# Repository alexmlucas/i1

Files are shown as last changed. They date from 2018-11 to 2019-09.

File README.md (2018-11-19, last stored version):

# i1
An accessible motion based guitar instrument

This project is part of PhD Research being undertaken by Queens University Belfast. 

i1 is a bespoke instrument designed for and with a musician with a physical disability. The intial concept is for the musician to use head and arm movement to trigger playback of chords on a virtual guitar.

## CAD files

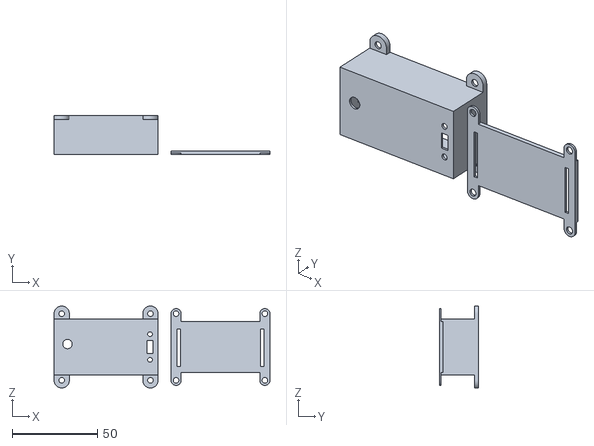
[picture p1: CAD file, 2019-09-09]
mechanical_design/wristband_enclosure.stl
126.5 x 23.0 x 48.0

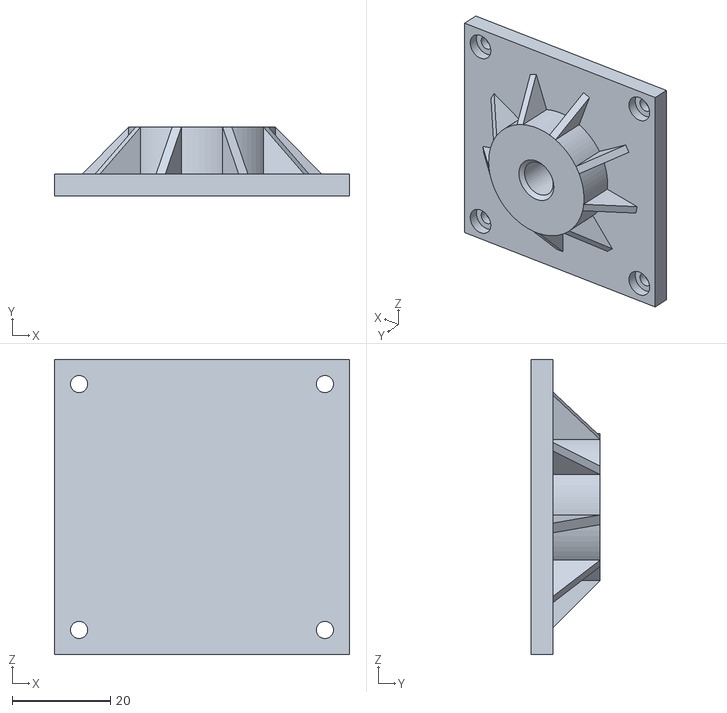
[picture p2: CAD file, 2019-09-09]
mechanical_design/camera_mount.stl
60.0 x 14.0 x 60.0

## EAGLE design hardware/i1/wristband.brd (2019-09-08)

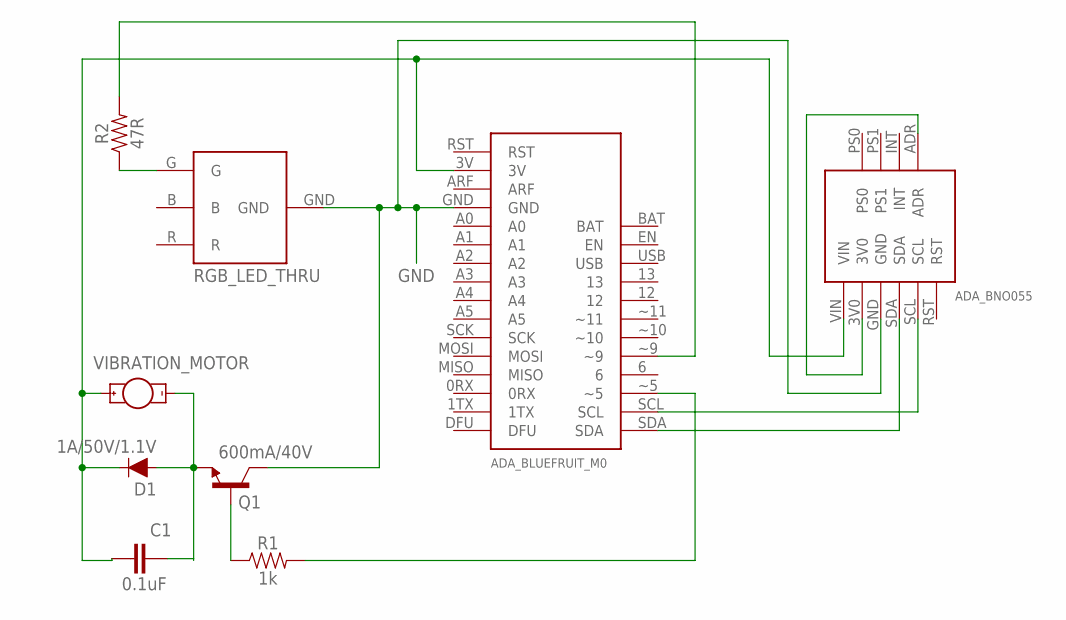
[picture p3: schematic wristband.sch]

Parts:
BF1: ADA_BLUEFRUIT_M0
BNO1: ADA_BNO055
C1: 0.1uF; CAP-PTH-SMALL-KIT
D1: 1A/50V/1.1V; DIODE-1N4001
Q1: 600mA/40V; TO-92
R1: 1k; AXIAL-0.3
R2: 47R; AXIAL-0.3
RGB_LED1: RGB_LED_THRU; RGB_LEB_RGB_2
U$1: VIBRATION_MOTOR

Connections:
GND: BF1.GND, BNO1.GND, Q1.1 (C), RGB_LED1.GND
unnamed: BF1.SDA, BNO1.SDA
unnamed: BF1.SCL, BNO1.SCL
unnamed: BF1.3V, BNO1.VIN, C1.1, D1.C, U$1.+
unnamed: BNO1.3V0, BNO1.ADR
unnamed: R2.P$1 (1), RGB_LED1.G
unnamed: BF1.~9, R2.P$2 (2)
unnamed: C1.2, D1.A, Q1.3 (E), U$1.-
unnamed: Q1.2 (B), R1.P$1 (1)
unnamed: BF1.~5, R1.P$2 (2)

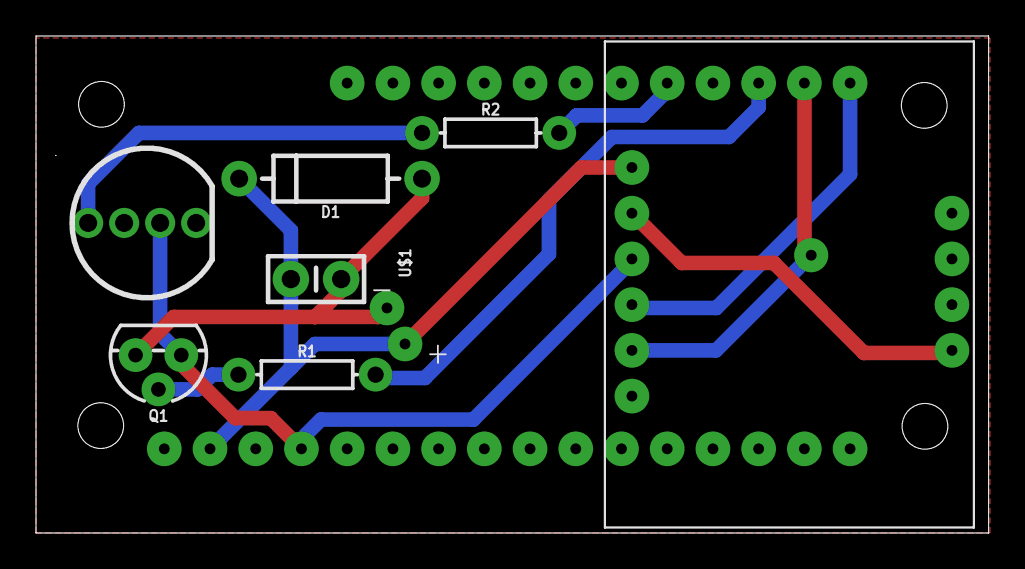
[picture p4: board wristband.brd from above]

Board: 2 copper layers, 52.9 x 27.6 mm, 9 parts (0 on the bottom side), 10 nets.

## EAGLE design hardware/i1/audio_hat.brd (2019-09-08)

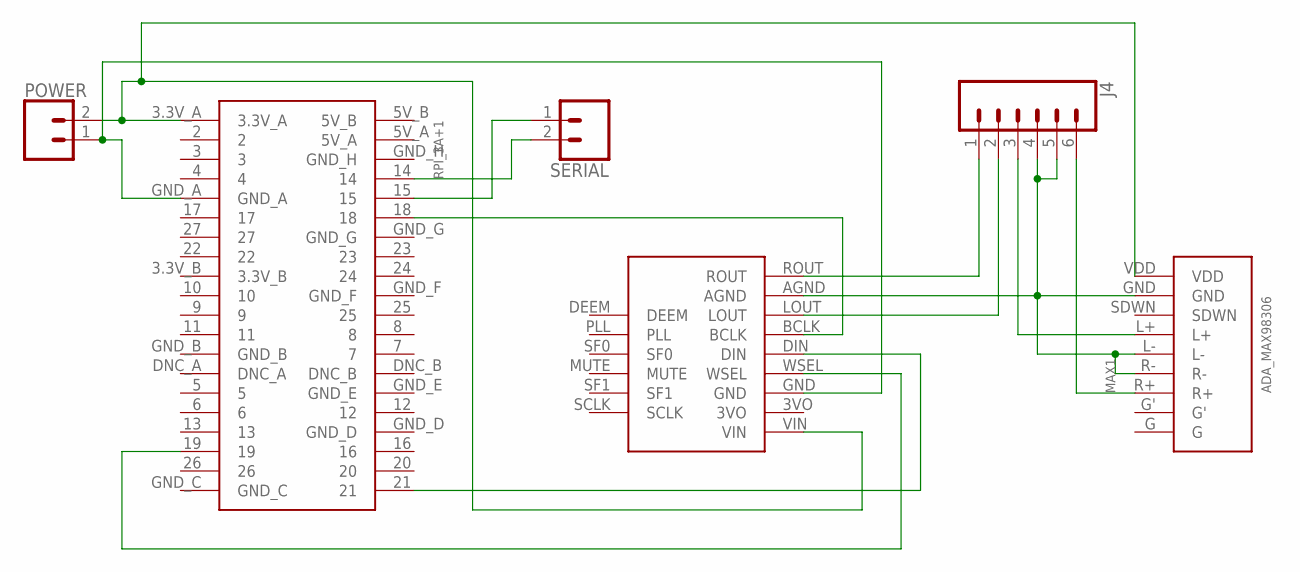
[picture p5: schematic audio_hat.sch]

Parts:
J4: CONN_06NO_SILK_NO_POP; 1X06_NO_SILK
MAX1: ADA_MAX98306
POWER: CONN_02; 1X02
RPI_3A+1: RPI_3A+
SERIAL: CONN_02; 1X02
UDA1: ADA_UDA1334

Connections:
unnamed: RPI_3A+1.19, UDA1.WSEL
unnamed: POWER.1, RPI_3A+1.GND_A, UDA1.GND
unnamed: MAX1.VDD, POWER.2, RPI_3A+1.3.3V_A, UDA1.VIN
unnamed: RPI_3A+1.21, UDA1.DIN
unnamed: J4.1, UDA1.ROUT
unnamed: J4.2, UDA1.LOUT
unnamed: J4.4, J4.5, MAX1.GND, MAX1.L-, MAX1.R-, UDA1.AGND
unnamed: J4.3, MAX1.L+
unnamed: RPI_3A+1.14, SERIAL.2
unnamed: J4.6, MAX1.R+
unnamed: RPI_3A+1.15, SERIAL.1
unnamed: RPI_3A+1.18, UDA1.BCLK

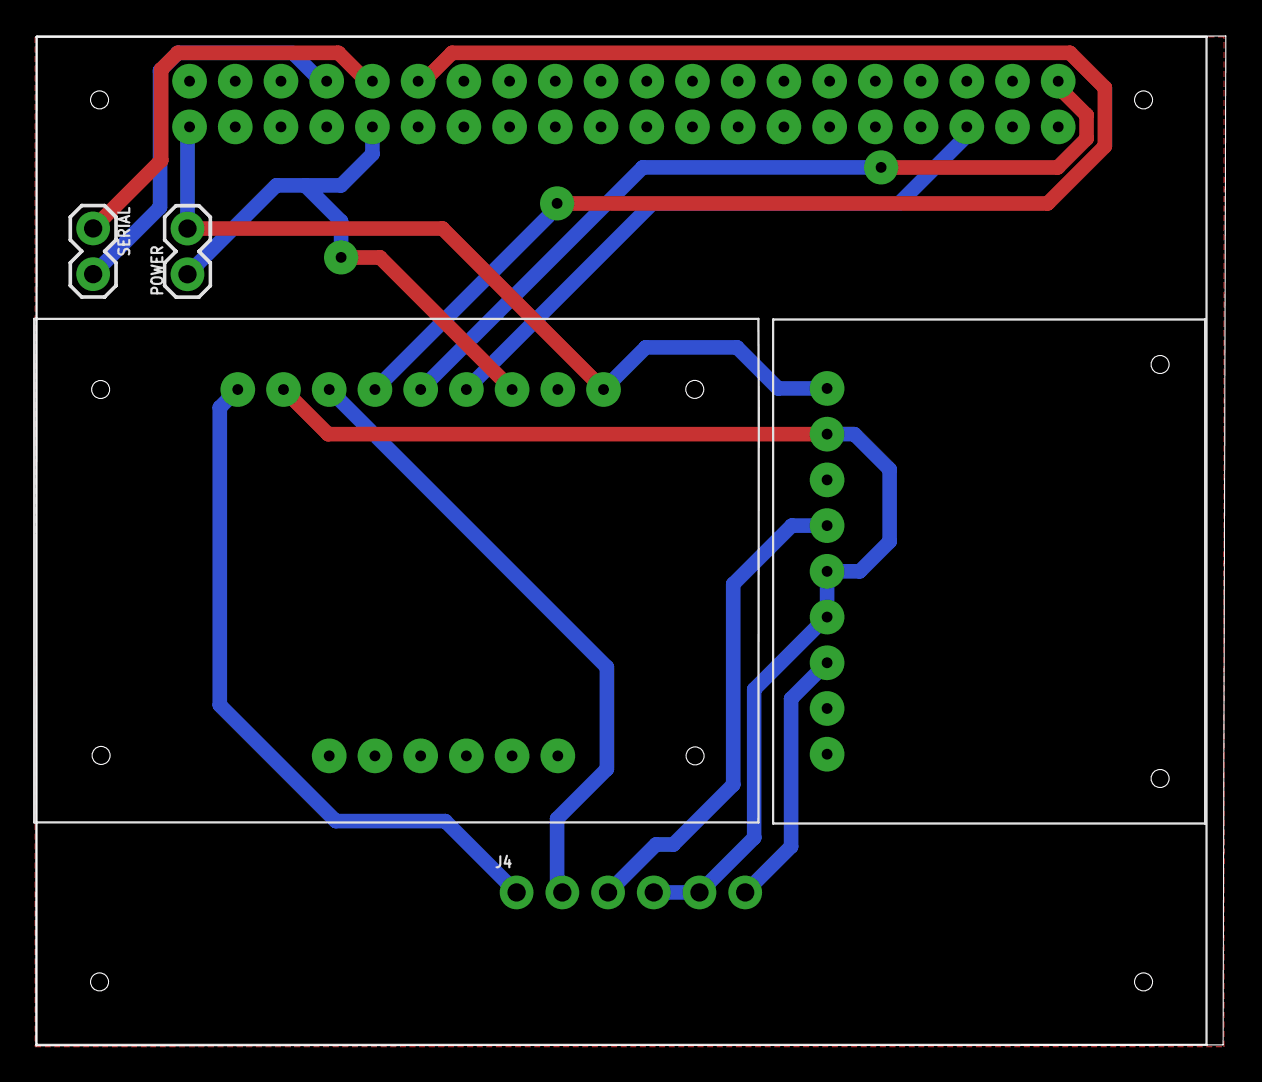
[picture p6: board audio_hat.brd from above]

Board: 2 copper layers, 66.1 x 56.1 mm, 6 parts (0 on the bottom side), 12 nets.

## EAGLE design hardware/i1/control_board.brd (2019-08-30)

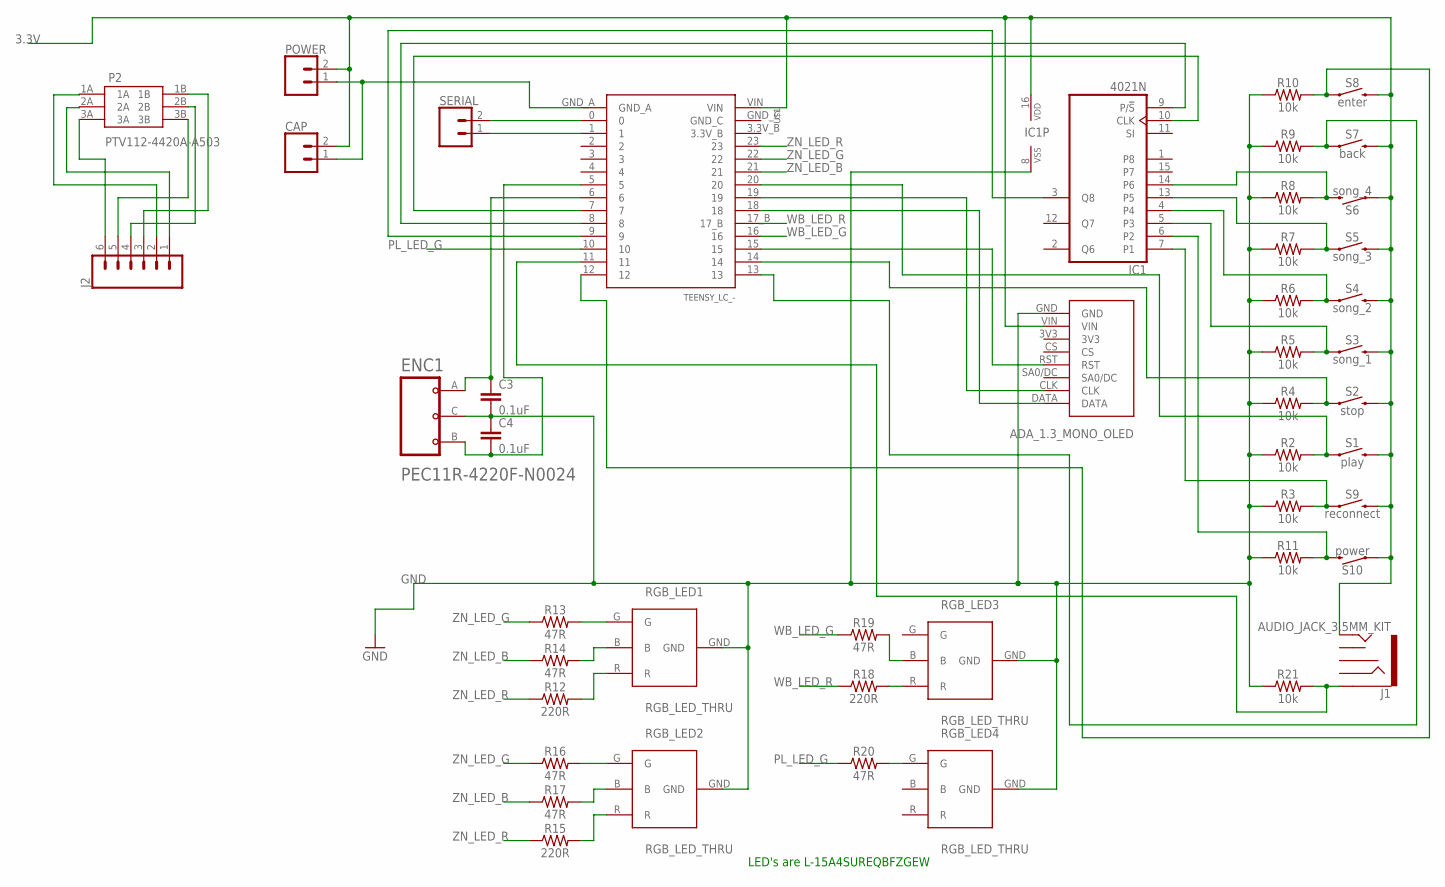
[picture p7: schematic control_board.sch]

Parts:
C3, C4: 0.1uF; CAP-PTH-SMALL-KIT
CAP: CONN_02; 1X02
ENC1: PEC11R-4220F-N0024
IC1: 4021N; DIL16
J1: AUDIO_JACK_3.5MM_KIT; AUDIO-JACK-KIT
J2: CONN_06NO_SILK_NO_POP; 1X06_NO_SILK
OLED1: ADA_1.3_MONO_OLED
P2: PTV112-4420A-A503; PTV122-4420A-A503
POWER: CONN_02; 1X02
R2, R3, R4, R5, R6, R7, R8, R9, R10, R11, R21: 10k; AXIAL-0.3
R12, R15, R18: 220R; AXIAL-0.3
R13, R14, R16, R17, R19, R20: 47R; AXIAL-0.3
RGB_LED1, RGB_LED2, RGB_LED3, RGB_LED4: RGB_LED_THRU; RGB_LEB_RGB_2
S1: play; TACTILE_SWITCH_PTH_6.0MM
S2: stop; TACTILE_SWITCH_PTH_6.0MM
S3: song_1; TACTILE_SWITCH_PTH_6.0MM
S4: song_2; TACTILE_SWITCH_PTH_6.0MM
S5: song_3; TACTILE_SWITCH_PTH_6.0MM
S6: song_4; TACTILE_SWITCH_PTH_6.0MM
S7: back; TACTILE_SWITCH_PTH_6.0MM
S8: enter; TACTILE_SWITCH_PTH_6.0MM
S9: reconnect; TACTILE_SWITCH_PTH_6.0MM
S10: power; TACTILE_SWITCH_PTH_6.0MM
SERIAL: CONN_02; 1X02
U$1: TEENSY_LC_-

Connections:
3.3V: CAP.2, IC1.16 (VDD), J1.TIP, OLED1.VIN, POWER.2, S1.3 (2), S2.3 (2), S3.3 (2), S4.3 (2), S5.3 (2), S6.1, S7.3 (2), S8.3 (2), S9.3 (2), S10.1, U$1.VIN
GND: C3.2, C4.1, CAP.1, ENC1.C (COMMON), IC1.8 (VSS), OLED1.GND, POWER.1, R2.P$1 (1), R3.P$1 (1), R4.P$1 (1), R5.P$1 (1), R6.P$1 (1), R7.P$1 (1), R8.P$1 (1), R9.P$1 (1), R10.P$1 (1), R11.P$1 (1), R21.P$1 (1), RGB_LED1.GND, RGB_LED2.GND, RGB_LED3.GND, RGB_LED4.GND, U$1.GND_A
unnamed: IC1.3 (Q8), U$1.9
unnamed: R13.P$2 (2), RGB_LED1.G
unnamed: R14.P$2 (2), RGB_LED1.B
unnamed: IC1.10 (CLK), U$1.7
unnamed: R12.P$2 (2), RGB_LED1.R
unnamed: R16.P$2 (2), RGB_LED2.G
unnamed: R17.P$2 (2), RGB_LED2.B
unnamed: IC1.9 (P/!S), U$1.8
unnamed: OLED1.DATA, U$1.18
unnamed: R4.P$2 (2), S2.1, U$1.14
unnamed: R9.P$2 (2), S7.1, U$1.13
unnamed: IC1.5 (P3), R5.P$2 (2), S3.1
unnamed: IC1.4, R6.P$2 (2), S4.1
unnamed: J1.SLEEVE, R21.P$2 (2), U$1.11
unnamed: IC1.13 (P5), R7.P$2 (2), S5.1
unnamed: IC1.14 (P6), R8.P$2 (2), S6.3 (2)
unnamed: SERIAL.1, U$1.1
unnamed: R10.P$2 (2), S8.1, U$1.12
unnamed: C3.1, ENC1.A (CHANNEL_A), U$1.6
unnamed: C4.2, ENC1.B (COMMON_B), U$1.5
unnamed: IC1.7 (P1), R3.P$2 (2), S9.1
unnamed: IC1.6 (P2), R11.P$2 (2), S10.3 (2)
unnamed: R15.P$2 (2), RGB_LED2.R
unnamed: R19.P$2 (2), RGB_LED3.B
unnamed: R18.P$2 (2), RGB_LED3.R
unnamed: R20.P$2 (2), RGB_LED4.G
unnamed: R2.P$2 (2), S1.1, U$1.20
unnamed: SERIAL.2, U$1.0
unnamed: J2.2, P2.1A
unnamed: OLED1.CLK, U$1.19
unnamed: OLED1.RST, U$1.15
unnamed: J2.1, P2.2A
unnamed: J2.6, P2.3A
unnamed: J2.4, P2.2B
unnamed: J2.5, P2.3B
unnamed: J2.3, P2.1B
PL_LED_G: R20.P$1 (1), U$1.10
WB_LED_G: R19.P$1 (1), U$1.16
WB_LED_R: R18.P$1 (1), U$1.17_B
ZN_LED_B: R14.P$1 (1), R17.P$1 (1), U$1.21
ZN_LED_G: R13.P$1 (1), R16.P$1 (1), U$1.22
ZN_LED_R: R12.P$1 (1), R15.P$1 (1), U$1.23

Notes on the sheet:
LED's are L-15A4SUREQBFZGEW

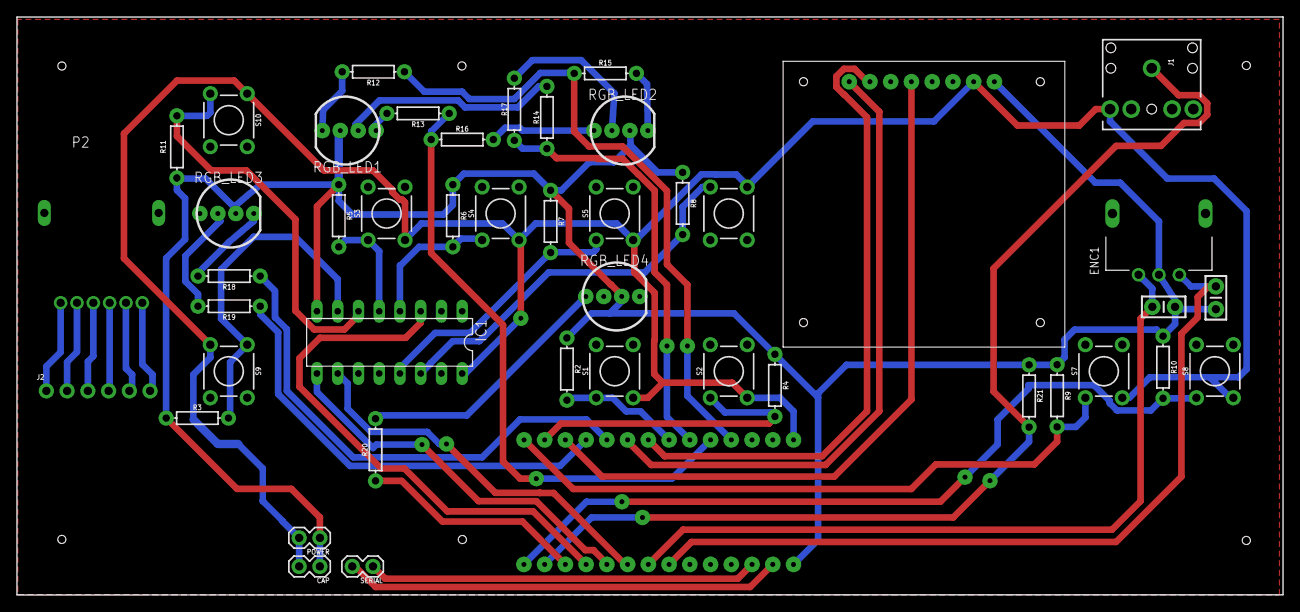
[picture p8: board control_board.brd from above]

Board: 2 copper layers, 155.0 x 70.8 mm, 46 parts (1 on the bottom side), 44 nets.

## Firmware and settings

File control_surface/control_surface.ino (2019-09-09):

// Display includes
#include <SPI.h>
#include <Wire.h>
#include <Adafruit_GFX.h>
#include <Adafruit_SSD1306.h>

// Control includes
#include "Control_Button.h"
#include "Shift_Register_Control_Button.h"
#include "Shift_Register_Menu_Button.h"
#include "Simple_Encoder.h"
#include "Single_Led.h"
#include "Rg_Led.h"
#include "Rgb_Led.h"

// Menu includes
#include "Menu_Page.h"
#include "Main_Page.h"
#include "List_Page.h"
#include "Selection_Page.h"
#include "Value_Page.h"
#include "Splash_Page.h"
#include "Menu_Controller.h"
#include "Parameter_Container.h"

#define OLED_RESET 15

// Create an instance of the display
Adafruit_SSD1306 display(OLED_RESET);

// Define the debounce time in milliseconds
#define DEBOUNCE_TIME 50

// Define the USB MIDI Note Velocity
#define NOTE_VELOCITY 100

// Define the encoder pins
#define ENCODER_PIN_A 5
#define ENCODER_PIN_B 6

// Define the button/switch pins
#define ACCESS_SWT_PIN 11
#define PLAY_BTN_PIN 20
#define STOP_BTN_PIN 14
#define BACK_BTN_PIN 13
#define ENTER_BTN_PIN 12

// Define button bits
#define RECONNECT_BTN_BIT 0
#define POWER_BTN_BIT 1
#define SONG_1_BTN_BIT 2
#define SONG_2_BTN_BIT 3
#define SONG_3_BTN_BIT 4
#define SONG_4_BTN_BIT 5

// Define the shift register pins.
#define SHIFT_REG_LATCH 8
#define SHIFT_REG_DATA 9
#define SHIFT_REG_CLOCK 7

// Define LED pins
#define ZN_LED_R A9
#define ZN_LED_G A8
#define ZN_LED_B A7
#define WB_LED_R A3
#define WB_LED_G A2
#define PL_LED_G 10

// Define play button states
#define PLAYING 0
#define PAUSED 1
#define STOPPED 2

// Define the min & max cursor values
#define MIN_CURSOR_VALUE 0
#define MAX_CURSOR_VALUE 2

// Define characters to be sent as serial strings.
const char RECONNECT_CHAR PROGMEM = 'a'; 
const char POWER_CHAR PROGMEM = 'b';
const char ACCESS_SWT_CHAR PROGMEM = 'c';
const char PLAY_CHAR PROGMEM = 'd';
const char STOP_CHAR PROGMEM = 'e';
const char SONG_1_CHAR PROGMEM = 'f';
const char SONG_2_CHAR PROGMEM = 'g';
const char SONG_3_CHAR PROGMEM = 'h';
const char SONG_4_CHAR PROGMEM = 'i';
const char BACK_CHAR PROGMEM = 'j';
const char ENTER_CHAR PROGMEM = 'k';

const static char song[] PROGMEM = "Song";
const static char guitar[] PROGMEM = "Guitar";
const char backing[] PROGMEM = "Backing";
const char master[] PROGMEM = "Master";
const static char zone[] PROGMEM = "Zone";
const static char mix_levels[] PROGMEM = "Mix Levels";
const char red_zone[] PROGMEM = "Red Zone";
const char green_zone[] PROGMEM = "Green Zone";
const char blue_zone[] PROGMEM = "Blue Zone";

const static char classic_rock[] PROGMEM = "Classic Rock";
const static char hard_rock[] PROGMEM = "Hard Rock";
const static char acoustic[] PROGMEM = "Acoustic";
const char scale[] PROGMEM = "Scale";
const char red_scale[] PROGMEM = "Red Scale";
const char green_scale[] PROGMEM = "Green Scale";
const char blue_scale[] PROGMEM = "Blue Scale";
const char root[] PROGMEM = "Root";
const char red_root[] PROGMEM = "Red Root";
const char green_root[] PROGMEM = "Green Root";
const char blue_root[] PROGMEM = "Blue Root";
const static char connecting[] PROGMEM = "Connecting";
const static char to_wristband[] PROGMEM = "to wristband,";
const static char please_wait[] PROGMEM = "please wait...";
const char sorry[] PROGMEM = "Sorry, I couldn't";
const char not_connect[] PROGMEM = "connect to";
const char the_wristband[] PROGMEM = "the wristband.";
const char not_load_song[] PROGMEM = "load song. Connect";
const char check_memory[] PROGMEM = "USB stick & reboot.";


//const char scale_param[] PROGMEM = "Major, Minor, Blues, Pent. Major, Pent. Minor, Major Chord, Minor Chord";
//const char root_param[] PROGMEM = "A, A#, B, C, C#, D, D#, E, F, F#, G, G#";

const char test_array[] PROGMEM = "test";
//const char flash_test PROGMEM = 'f';

// An array of constant pointers to constant chars?
const static char *const main_menu_txt[] PROGMEM = {song, guitar, zone, mix_levels};
const char *const guitar_menu_txt[] PROGMEM = {guitar, classic_rock, hard_rock, acoustic};
const char *const zone_menu_txt[] PROGMEM = {zone, red_zone, green_zone, blue_zone};
const char *const red_zone_menu_txt[] PROGMEM = {red_zone, scale, root};
const char *const green_zone_menu_txt[] PROGMEM = {green_zone, scale, root};
const char *const blue_zone_menu_txt[] PROGMEM = {blue_zone, scale, root};
const char *const red_scale_menu_txt[] PROGMEM = {red_scale};
const char *const green_scale_menu_txt[] PROGMEM = {green_scale};
const char *const blue_scale_menu_txt[] PROGMEM = {blue_scale};
const char *const red_root_menu_txt[] PROGMEM = {red_root};
const char *const green_root_menu_txt[] PROGMEM = {green_root};
const char *const blue_root_menu_txt[] PROGMEM = {blue_root};

const char *const mix_levels_menu_txt[] PROGMEM = {mix_levels, guitar, backing, master};
const char *const guitar_level_menu_txt[] PROGMEM = {guitar}; 
const char *const backing_level_menu_txt[] PROGMEM = {backing}; 
const char *const master_level_menu_txt[] PROGMEM = {master};

const static char *const reconnect_menu_txt[] PROGMEM = {connecting, to_wristband, please_wait};
const char *const connection_fail_menu_txt[] PROGMEM = {sorry, not_connect, the_wristband};
const char *const song_fail_menu_txt[] PROGMEM = {sorry, not_load_song, check_memory};

// const char* = a pointer to a constant char.
// char* const = a constant pointer to a char. (This pointer cannot be changed)
// const char* const = a constant pointer to a constant char (Nothing can be changed after declaration, therefore it can sit in program memory)
// const char* const my_array[] = a constant pointer to an array of constant chars (Nothing can be changed after declaration, therefore it can sit in program memory)

const char* const mix_levels_param_txt[] PROGMEM = {"0", "0.1", "0.2", "0.3", "0.4", "0.5", "0.6", "0.7", "0.8", "0.9", "1"};
const char* const scales_param_txt[] PROGMEM = {"Pent. Major", "Pent. Minor", "Blues", "Major Chord", "Minor Chord"};
const char* const root_param_txt[] PROGMEM = {"E", "F", "F#", "G", "G#", "A", "A#", "B", "C", "C#", "D", "D#"};

// Define a variable to hold the data from the shift register
byte shift_reg_byte = 0;

// Create Simple_Encoder instance.
Simple_Encoder selection_encoder;

// A pointer to an array of constant pointers to constant chars.
const char *const *menu_text_pointer;

// Byte for storing incoming serial data.
char incoming_byte_1;
char incoming_byte_2;
char incoming_byte_3;

// String representing the current menu location.
char current_menu_location[] = {""};

// Buffer for reading menu text.
char string_buffer[30];

// Read and monitior encoder position.
int current_encoder_position, last_encoder_position;

Menu_Controller menu_controller(MIN_CURSOR_VALUE, MAX_CURSOR_VALUE);      // Create an instance of Menu_Controller.
Parameter_Container parameter_container;                // Create an instance of Parameter_Container.
Parameter_Container *p_parameter_container;

// *** Initialise Menu_Page(s) ***
Main_Page main_menu(&menu_controller, &parameter_container);
Selection_Page guitar_menu(&menu_controller, &parameter_container);
List_Page zone_menu(&menu_controller, &parameter_container);
List_Page mix_levels_menu(&menu_controller, &parameter_container);
List_Page red_zone_menu(&menu_controller, &parameter_container);
List_Page green_zone_menu(&menu_controller, &parameter_container);
List_Page blue_zone_menu(&menu_controller, &parameter_container);
Value_Page red_scale_menu(&menu_controller, &parameter_container);
Value_Page red_root_menu(&menu_controller, &parameter_container);
Value_Page green_scale_menu(&menu_controller, &parameter_container);
Value_Page green_root_menu( &menu_controller, &parameter_container);
Value_Page blue_scale_menu(&menu_controller, &parameter_container);
Value_Page blue_root_menu(&menu_controller, &parameter_container);
Value_Page guitar_level_menu(&menu_controller, &parameter_container);
Value_Page backing_level_menu(&menu_controller, &parameter_container);
Value_Page master_level_menu(&menu_controller, &parameter_container);
Splash_Page reconnect_menu(&menu_controller, &parameter_container);
Splash_Page connection_fail_menu(&menu_controller, &parameter_container);
Splash_Page song_fail_menu(&menu_controller, &parameter_container);

// *** Initialise Pointers to Sub Menu_Page(s) ***  
Menu_Page *p_main_sub_menus[] = {&guitar_menu, &zone_menu, &mix_levels_menu};                        
Menu_Page *p_zone_sub_menus[] = {&red_zone_menu, &green_zone_menu, &blue_zone_menu};
Menu_Page *p_red_zone_sub_menus[] = {&red_scale_menu, &red_root_menu};
Menu_Page *p_green_zone_sub_menus[] = {&green_scale_menu, &green_root_menu};
Menu_Page *p_blue_zone_sub_menus[] = {&blue_scale_menu, &blue_root_menu};    
Menu_Page *p_mix_levels_sub_menus[] = {&guitar_level_menu, &backing_level_menu, &master_level_menu};

Menu_Page *p_current_menu_page;                                           // Create a pointer to the currently selected menu page.
Menu_Page *p_previous_menu_page;                                          // Create a pointer to the previously selected menu page.
Menu_Page *p_wristband_return_page;                                       // Creat a pointer to the page to retrn to after wristabnd conneciton messages have been displayed.

// *** Create Simple_Button instances ***
Control_Button access_switch(ACCESS_SWT_PIN, DEBOUNCE_TIME, &menu_controller, &parameter_container, &parameter_container.m_zone, 0);
Control_Button play_button(PLAY_BTN_PIN, DEBOUNCE_TIME, &menu_controller, &parameter_container, &parameter_container.m_play, 1);
Control_Button stop_button(STOP_BTN_PIN, DEBOUNCE_TIME, &menu_controller, &parameter_container, &parameter_container.m_play, 0);
Menu_Button back_button(BACK_BTN_PIN, DEBOUNCE_TIME, &menu_controller);
Menu_Button enter_button(ENTER_BTN_PIN, DEBOUNCE_TIME, &menu_controller);

// *** Create Shift_Register_Button instances ***
Shift_Register_Control_Button reconnect_button(RECONNECT_BTN_BIT, DEBOUNCE_TIME, &menu_controller, &parameter_container, &parameter_container.m_reconnect, 0);
Shift_Register_Control_Button power_button(POWER_BTN_BIT, DEBOUNCE_TIME, &menu_controller, &parameter_container, &parameter_container.m_power, 0);
Shift_Register_Control_Button song_1_button(SONG_1_BTN_BIT, DEBOUNCE_TIME, &menu_controller, &parameter_container, &parameter_container.m_song, 0);
Shift_Register_Control_Button song_2_button(SONG_2_BTN_BIT, DEBOUNCE_TIME, &menu_controller, &parameter_container, &parameter_container.m_song, 1);
Shift_Register_Control_Button song_3_button(SONG_3_BTN_BIT, DEBOUNCE_TIME, &menu_controller, &parameter_container, &parameter_container.m_song, 2);
Shift_Register_Control_Button song_4_button(SONG_4_BTN_BIT, DEBOUNCE_TIME, &menu_controller, &parameter_container, &parameter_container.m_song, 3);

// *** Create Led instances ***
int zone_led_pins[] = {ZN_LED_R, ZN_LED_G, ZN_LED_B};
int wristband_led_pins[] = {WB_LED_R, WB_LED_G};

int RG_RED[] = {255, 0};
int RG_GREEN[] = {0, 255};
int RG_OFF[] = {0, 0};

int RGB_RED[] = {255, 0, 0};
int RGB_GREEN[] = {0, 255, 0};
int RGB_BLUE[] = {0, 0, 255};
int RGB_OFF[] = {0, 0, 0};

int *p_rgb_red = RGB_RED; 
int *p_rgb_blue = RGB_BLUE; 
bool FLASH_ALL[] = {true, true, true};

Single_Led play_led;
Rg_Led wristband_leds;
Rgb_Led zone_leds;

// Timer variables for deactivating Splash Pages
int time_splash_loaded_ms;
int SPLASH_DISPLAY_TIME = 3000;
int current_time_ms;
bool splash_page_loaded;

// Variable for tracking whether or not a song is loaded.
bool song_loaded = false;
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
void loop() {
  
  if(splash_page_loaded){
    current_time_ms = millis();

    if((current_time_ms - time_splash_loaded_ms) > SPLASH_DISPLAY_TIME){
      // This method will also set the redraw display flag.
      menu_controller.set_currently_selected_menu(p_wristband_return_page);
      splash_page_loaded = false;
    }
  }
  
  if(menu_controller.get_redraw_display_flag() == true){
    // Assign pointer to the currently selected menu.
    p_current_menu_page = (Menu_Page*)menu_controller.get_currently_selected_menu();
    
    if(p_current_menu_page != p_previous_menu_page){
      menu_controller.set_cursor_position(0);           // The menu page has changed so reset the cursor position. 
    }
    
    p_current_menu_page->draw(display);
    menu_controller.set_redraw_display_flag(false);

    p_previous_menu_page = p_current_menu_page;           // Update the previous menu page.
  }
  
  // Set the latch pin to 1 to collect parallel data.
  digitalWrite(SHIFT_REG_LATCH, 1);
  delayMicroseconds(1);
  // Set the latch pin to to 0 to transmit data serially.
  digitalWrite(SHIFT_REG_LATCH, 0);
  // Collect the register as a byte.
  shift_reg_byte = shift_in(SHIFT_REG_DATA, SHIFT_REG_CLOCK);

  // Process the shift register buttons
  reconnect_button.check_button_pressed(shift_reg_byte);
  power_button.check_button_pressed(shift_reg_byte);
  song_1_button.check_button_pressed(shift_reg_byte);
  song_2_button.check_button_pressed(shift_reg_byte);
  song_3_button.check_button_pressed(shift_reg_byte);
  song_4_button.check_button_pressed(shift_reg_byte);
  
  // Process the buttons connected directly to the microcontroller
  access_switch.check_button_pressed();
  play_button.check_button_pressed();
  stop_button.check_button_pressed();
  back_button.check_button_pressed();
  enter_button.check_button_pressed();
  
  // Process the leds that need to flash.
  play_led.update_flashing();
  wristband_leds.update_flashing();
 
  if(Serial1.available() > 0){             // If serial data is available...
    serial_parser();                      // ...call the parser.
  }

  // Get the current encoder position
  current_encoder_position = selection_encoder.track_position();

  // Has the value changed?
  if(current_encoder_position != last_encoder_position){
    // Print the value.
    Serial1.println(current_encoder_position);
    // Update the last known value.
    last_encoder_position = current_encoder_position;
  }
}

byte shift_in(int incoming_data_pin, int incoming_clock_pin){
  int i;
  int temp = 0;
  //int pin_state;
  byte data_in = 0;

  // Set the clock pin to high in preparation for
  // reading the first value.
  digitalWrite(incoming_clock_pin, 1);

  for(i = 7; i >= 0; i--){
    // The data pin changes value to the next pin of the
    // shift register on every transition from HIGH to LOW
    digitalWrite(incoming_clock_pin, 0);
    delayMicroseconds(0.2);
    temp = digitalRead(incoming_data_pin);
    // If the temp value is HIGH then...
    if(temp){
      // ...set the corresponding bit to 1.
      // The OR operation allows us to maintain the state of the other bits.
      data_in = data_in | (1 << i);
    }
    // Set the clock pin to high in preparation for
    // reading the next value.
    digitalWrite(incoming_clock_pin, 1);
  }
  return data_in;
}

void print_bits(byte incoming_byte){
  for(int i = 7; i >= 0; i--){
    Serial1.print(bitRead(incoming_byte,i));
  }
  Serial1.println();
}

void enter_pressed(Menu_Controller* p_menu_controller){                                // Function expects a pointer to a Menu_Controller.
  Menu_Page *m_menu = (Menu_Page*)p_menu_controller->m_currently_selected_menu;        // Create local pointer to the currently selected Menu_Page, via the Menu_Controller pointer.
  
  if(m_menu->m_enter_enabled){                                                         // if the currently selected menu has an on_enter() function...
    m_menu->on_enter();                                                                // ... call it.
  }                                                                   
}

void back_pressed(Menu_Controller* p_menu_controller){                                 // Function expects a pointer to a Menu_Controller.
  Menu_Page *m_menu = (Menu_Page*)p_menu_controller->m_currently_selected_menu;        // Create local pointer to the currently selected Menu_Page, via the Menu_Controller pointer.
  
  if(m_menu->m_back_enabled){                                                          // if the currently selected menu has an on_enter() function...
    m_menu->on_back();                                                                 // ... call it.
  }                                                      
}

void play_pressed(Single_Led *led, Parameter_Container *parameter_container, Parameter *parameter_struct, int parameter_value){
  // check to see if song is loaded before acting on play button events
  if(parameter_container->m_song_loaded.value == 1){
    switch(parameter_struct->value){
      case 0:
        parameter_container->set_and_send_parameter(parameter_struct, 1);         // Playback is currently stopped, so start it.
        led->set_on(true);                                                        // Update the led
        break;
      case 1:
        parameter_container->set_and_send_parameter(parameter_struct, 2);         // Song is playing already, so pause it.
        led->set_flashing(true);                                                  // Update the led
        break;
      case 2:
        parameter_container->set_and_send_parameter(parameter_struct, 1);         // Song is paused, so commence playback.
        led->set_on(true);                                                        // Update the led
        break;
    }
  }
}

void stop_pressed(Single_Led *led, Parameter_Container *parameter_container, Parameter *parameter_struct, int parameter_value){
  // check to see if song is loaded before acting on play button events
  if(parameter_container->m_song_loaded.value == 1){
    if(parameter_struct->value){
      parameter_container->set_and_send_parameter(parameter_struct, 0);          // Currently playing the song, so stop it.
      led->set_on(false);                                               
    }
  }
}

void song_pressed(Single_Led *led, Parameter_Container *parameter_container, Parameter *parameter_struct, int parameter_value){
  led->set_on(false);                                                                       // switch off the LED, which in this case is the play LED.
  parameter_container->set_and_send_parameter(&parameter_container->m_play, 0);             // set the play state to off.
  parameter_container->set_and_send_parameter(parameter_struct, parameter_value);           // update the currently selected song
}

void access_switch_pressed(Single_Led *led, Parameter_Container *parameter_container, Parameter *parameter_struct, int parameter_value){
  Rgb_Led *rgb_led = (Rgb_Led*)led;        // Create local pointer to the currently selected Menu_Page, via the Menu_Controller pointer.

  switch(parameter_struct->value){
    case 0:
      parameter_container->set_and_send_parameter(parameter_struct, 1);         // Increment parameter value
      rgb_led->set_colour(RGB_GREEN);                                           // Update the led
      break;
    case 1:
      parameter_container->set_and_send_parameter(parameter_struct, 2);         // Increment parameter value
      rgb_led->set_colour(RGB_BLUE);                                            // Update the led
      break;
    case 2:
      parameter_container->set_and_send_parameter(parameter_struct, 0);         // Reset parameter value to 0
      rgb_led->set_colour(RGB_RED);                                             // Update the led
      break;
  }
}
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

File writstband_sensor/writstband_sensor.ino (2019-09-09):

/*#include <Adafruit_ATParser.h>
#include <Adafruit_BLEMIDI.h>
#include <Adafruit_BLEBattery.h>
#include <Adafruit_BLEGatt.h>
#include <Adafruit_BLEEddystone.h>*/

#include <Adafruit_BLE.h>
#include <Adafruit_BluefruitLE_UART.h>
#include <Adafruit_BluefruitLE_SPI.h>
#include "Adafruit_BLEGatt.h"
#include "BluefruitConfig.h"

#if SOFTWARE_SERIAL_AVAILABLE
  #include <SoftwareSerial.h>
#endif

#include <Wire.h>
#include <Adafruit_Sensor.h>
#include <Adafruit_BNO055.h>
#include <utility/imumaths.h>
  
Adafruit_BNO055 bno = Adafruit_BNO055(55);

#define BNO_SERVICE_UUID128     "36-9B-19-D1-A3-40-49-7E-A8-CE-DA-FA-92-D7-67-93"
#define BNO_YAW_CHAR_UUID128    "94-34-C1-6F-B0-11-45-90-8B-E3-2F-97-D6-3C-C5-49"
#define BNO_MOTOR_CHAR_UUID128  "14-EC-99-94-49-32-4B-DA-99-7A-B3-D0-52-CD-74-21"


// Create the bluefruit object, either software serial...uncomment these lines
/*
SoftwareSerial bluefruitSS = SoftwareSerial(BLUEFRUIT_SWUART_TXD_PIN, BLUEFRUIT_SWUART_RXD_PIN);
Adafruit_BluefruitLE_UART ble(bluefruitSS, BLUEFRUIT_UART_MODE_PIN,
                      BLUEFRUIT_UART_CTS_PIN, BLUEFRUIT_UART_RTS_PIN);
*/

/* ...or hardware serial, which does not need the RTS/CTS pins. Uncomment this line */
// Adafruit_BluefruitLE_UART ble(BLUEFRUIT_HWSERIAL_NAME, BLUEFRUIT_UART_MODE_PIN);

/* ...hardware SPI, using SCK/MOSI/MISO hardware SPI pins and then user selected CS/IRQ/RST */
Adafruit_BluefruitLE_SPI ble(BLUEFRUIT_SPI_CS, BLUEFRUIT_SPI_IRQ, BLUEFRUIT_SPI_RST);

/* ...software SPI, using SCK/MOSI/MISO user-defined SPI pins and then user selected CS/IRQ/RST */
//Adafruit_BluefruitLE_SPI ble(BLUEFRUIT_SPI_SCK, BLUEFRUIT_SPI_MISO,
//                             BLUEFRUIT_SPI_MOSI, BLUEFRUIT_SPI_CS,
//                             BLUEFRUIT_SPI_IRQ, BLUEFRUIT_SPI_RST);

// A small helper
void error(const __FlashStringHelper*err) {
  Serial.println(err);
  while (1);
}

/* The service information */

int32_t bnoServiceId;
int32_t bnoYawCharId;
int32_t bnoMotorCharId;
/**************************************************************************/
/*!
    @brief  Sets up the HW an the BLE module (this function is called
            automatically on startup)
*/
/**************************************************************************/
const int motorPin = 5;
const int ledPin = 9;
int current_guitar_string = 0;
int last_guitar_string = 0;
int led_flash_time = 2000;
int last_led_flash_time;
int led_on_time = 20;
bool switch_off_led = false;

void setCharValue(int32_t charId, float value, int precision=2){
  // Set the specified characteristic to a floating point value.
  // Construct an AT+GATTCHAR command to send the float value.
  // The command will look like: AT+GATTCHAR=<charId>,<value as array of bytes>
  ble.print(F("AT+GATTCHAR="));
  ble.print(charId, DEC);
  ble.print(F(","));
  ble.println(value, precision);
  
  if (!ble.waitForOK())
  {
    Serial.println(F("Failed to get response!"));
  }
}

void setup(void)
{
  pinMode(motorPin, OUTPUT);
  pinMode(ledPin, OUTPUT);
  digitalWrite(motorPin, LOW);
  analogWrite(ledPin, 5);
  
  // while (!Serial); // required for Flora & Micro
  delay(500);

  boolean success;

  Serial.begin(115200);

  randomSeed(micros());

  /* Initialise the module */
  Serial.print(F("Initialising the Bluefruit LE module: "));

  if ( !ble.begin(VERBOSE_MODE) )
  {
    error(F("Couldn't find Bluefruit, make sure it's in CoMmanD mode & check wiring?"));
  }
  Serial.println( F("OK!") );

  /* Perform a factory reset to make sure everything is in a known state */
  Serial.println(F("Performing a factory reset: "));
  if (! ble.factoryReset() ){
       error(F("Couldn't factory reset"));
  }

  /* Disable command echo from Bluefruit */
  ble.echo(false);

  Serial.println("Requesting Bluefruit info:");
  /* Print Bluefruit information */
  ble.info();

  // this line is particularly require for Flora, but is a good idea
  // anyways for the super long lines ahead!
  // ble.setInterCharWriteDelay(5); // 5 ms

  /* Change the device name to make it easier to find */
  Serial.println(F("Setting device name to 'BNO': "));

  if (! ble.sendCommandCheckOK(F("AT+GAPDEVNAME=BNO")) ) {
    error(F("Could not set device name?"));
  }

  /* Add the Heart Rate Service definition */
  /* Service ID should be 1 */
  Serial.println(F("Adding the BNO Service definition: "));
  success = ble.sendCommandWithIntReply( F("AT+GATTADDSERVICE=UUID128=" BNO_SERVICE_UUID128), &bnoServiceId);
  if (! success) {
    error(F("Could not add BNO service"));
  }

  /* Add the Heart Rate Measurement characteristic */
  /* Chars ID for Measurement should be 1 */
  Serial.println(F("Adding the BNO Yaw characteristic: "));
  success = ble.sendCommandWithIntReply( F("AT+GATTADDCHAR=UUID128=" BNO_YAW_CHAR_UUID128 ", PROPERTIES=0x12, MIN_LEN=2, MAX_LEN=3, VALUE=00=40"), &bnoYawCharId);
    if (! success) {
    error(F("Could not add BNO Yaw characteristic"));
  }

  /* Add the Body Sensor Location characteristic */
  /* Chars ID for Body should be 2 */
  Serial.println(F("Adding the BNO Motor characteristic: "));
  success = ble.sendCommandWithIntReply( F("AT+GATTADDCHAR=UUID128=" BNO_MOTOR_CHAR_UUID128 ", PROPERTIES=0x04, MIN_LEN=1, VALUE=20"), &bnoMotorCharId);
    if (! success) {
    error(F("Could not add BNO Motor characteristic"));
  }

  /* Reset the device for the new service setting changes to take effect */
  Serial.print(F("Performing a SW reset (service changes require a reset): "));
  ble.reset();

  Serial.println();

  /* Initialise the sensor */
  if(!bno.begin())
  {
    /* There was a problem detecting the BNO055 ... check your connections */
    Serial.print("Ooops, no BNO055 detected ... Check your wiring or I2C ADDR!");
    while(1);
  }
  
  delay(1000);
  
  bno.setExtCrystalUse(true);
  setCharValue(bnoMotorCharId, current_guitar_string);

  last_led_flash_time = millis();
}
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

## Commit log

2018-11-20 code relating to serial communication has been updated to allow consistent readings of two IMU's
2018-11-26 First commit headset sensor
2018-11-26 First commit of headset sensor code with correct file name
2018-11-26 First commit of wristband sensor code
2018-11-28 First commit of headset 3D model
    Fusion 360 file format
    [headsetModel.f3d]
2018-11-28 First commit of headset 3D model
    IGES file, which is hopefully compatible with Free Cad
    [headsetModel.iges]
2018-12-20 Fixed string trigger bug
    It wasn't possible to re-trigger a string on the outer extremities of the chord. As a result of the fix for this bug the Segmenter class has been split into two, StringSegementer and ChordSegementer.
    [main.py]
2018-12-20 Reliability improvements
    Also removed display code and replaced with LED lighting code
2018-12-20 Reliability improvements
    Also replaced display code with code for LED lighting.
2019-01-29 Update main.py
    Removed headset IMU, replaced with sip/puff switch. Added bluetooth support.
    [main.py]
2019-01-31 Now communicating with wristband via Bluetooth UART.
2019-01-31 Bluetooth UART implemented
    Allows triggering of motor too!
2019-01-31 Reverted to using Bluetooth characteristics for comms
    [main.py]
2019-01-31 Adding code for sip sensor
    An arduino sketch.
2019-01-31 Remove headset model
    No longer required.
    [headsetModel.f3d]
2019-01-31 Remove headset model
    No longer required
    [headsetModel.iges]
2019-03-13 Implement encoder functionality
2019-04-11 First attempt at arduino control scanning
2019-04-17 First commit of control board schematic
    [control_board.sch]
2019-04-17 Commit original control board schematic as .pdf
2019-04-19 Implement menu hierarchy, develop Button
    Gave Menu_Page pointer to subpages - this is how the menu hierarchy will be built.
    Enter button can now call the on_enter() function of the currently selected Menu_Page
2019-04-20 Add arduino sketch folder
2019-04-20 Call on_encoder() method from encoder class
2019-04-21 Refactored button classes.
    Serial messages now sent from control buttons.
2019-04-21 Add LED lighting through Serial comms.
2019-04-23 Control Button aware of its parameter
2019-04-23 Refresh display when song button is pressed.
2019-04-23 New version of buttons sending serial msg
2019-04-24 Use Teensy LC rather than ATMEGA328
    [control_board.sch]
2019-04-24 Change LED resistor values.
    helps keep LEDs lit at a consistent brightness.
    [control_board.sch]
2019-04-24 Send LED lighting messages from RPi
2019-04-25 Implement inheritance in LED class
2019-04-25 Control Buttons own led pointer
2019-04-26 Fix stop button not switching off play led
2019-04-26 Fix crash on zone led set colour
    [Rgb_Led.cpp]
2019-04-26 Control menu and wristband LEDs via serial
2019-04-26 Send song data to Teensy when requested
2019-04-26 Write Serial data from Teensy to text file
2019-04-27 Light LEDs based on intial parameter values
2019-05-02 Respond to song parameter, fix serial reading bug
    [Parameter_Container.cpp]
2019-05-11 update play state and switch off play led when song changed
2019-05-12 Tidy up; delete unnecessary files
    [control_surface.sch]
2019-05-15 Fix bug; level didn't change with song selection
    [main.py, parameter_manager.py, song_player.py]
2019-05-15 Fix junk incoming serial messages
    Added a slight delay between reading each byte. Perhaps a slower BAUD rate would be better?
    [control_surface.ino]
2019-05-19 Fix bug, menu not chaging after wristband connection
    [control_surface.ino]
2019-05-20 fix bug multiple subscriptions to yaw characteristic
    [main.py, parameter_manager.py]
2019-07-22 Update control_surface.ino
    Change button configuration
2019-07-23 First commit of Eagle hardware files
    [control_board.brd, control_board.sch, control_surface.sch]
2019-07-24 Split into two boards
    Separate RPi audio hat
    [audio_hat.brd, audio_hat.sch, control_board.sch]
2019-07-25 Correct via routing on top layer
    [audio_hat.brd, audio_hat.sch]
2019-07-30 Re-space controls - add mounting holes for RPi
    Add audio hat
    [control_board.brd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]
2019-08-14 Audio hat now makes use of PCB via rivets
    [audio_hat.brd, audio_hat.sch]
2019-08-26 Add wristband schematic and board layout
    [audio_hat.brd, control_board.brd, control_board.sch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]
2019-08-30 Teensy respond correctly to transport messages.
    [Parameter_Container.cpp, control_surface.ino]
2019-08-30 Tighten components to allow for mounting holes
    [wristband.brd, wristband.sch]
2019-08-30 Change pad size of LEDs
    [control_board.brd, control_board.sch]
2019-08-30 Light LED on power
2019-09-08 Final tweaks for mechanical fit.
    [audio_hat.brd, wristband.brd]
2019-09-09 Change song fail message, fix zone previous menu bug
    [control_surface.ino]
2019-09-09 Reduce brightness of power LED
2019-09-09 fix incorrect note bug
    [guitar.py, main.py, parameter_manager.py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]
2019-09-09 Initial commit of mechanical design
    [camera_mount.stl, wristband_enclosure.stl]

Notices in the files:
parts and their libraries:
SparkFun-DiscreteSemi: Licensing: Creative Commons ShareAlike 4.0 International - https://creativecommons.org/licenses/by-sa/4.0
